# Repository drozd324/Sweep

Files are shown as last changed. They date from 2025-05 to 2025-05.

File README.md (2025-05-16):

Below the first two pictures show my modifications to sweep v2.2 .
Below that again is the original readme.

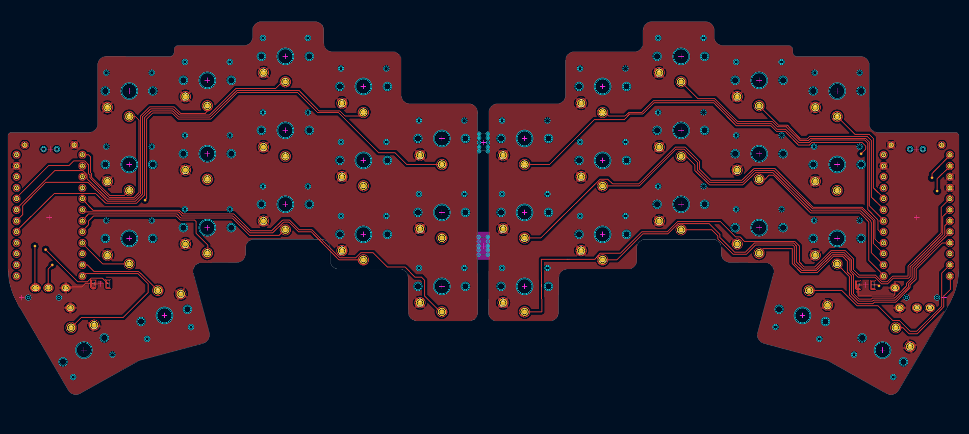
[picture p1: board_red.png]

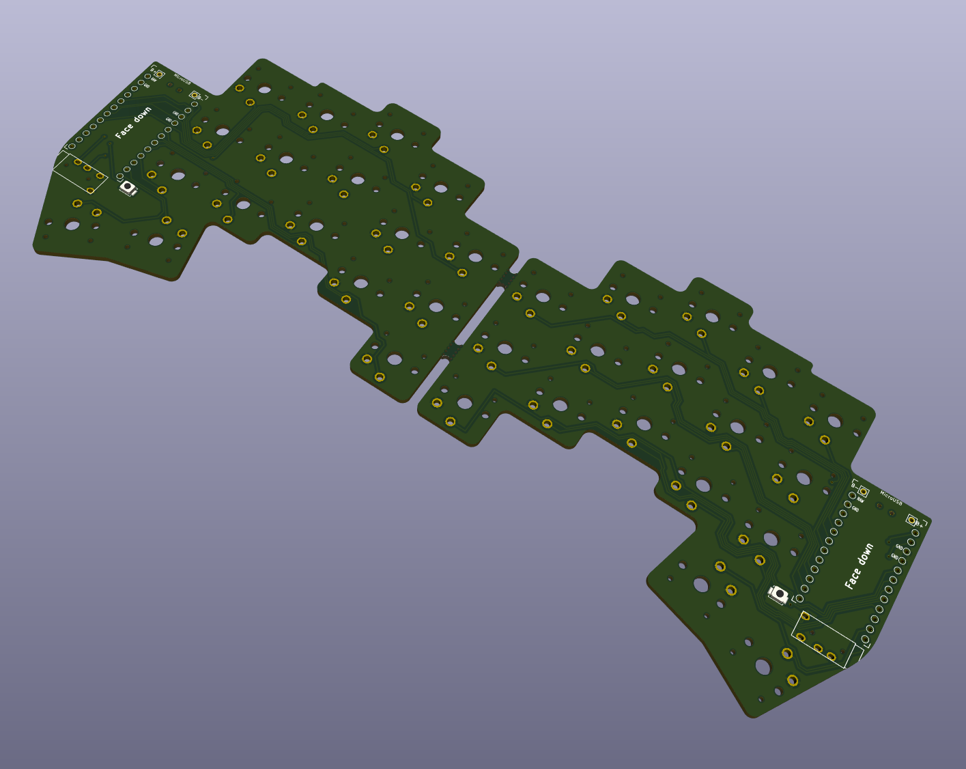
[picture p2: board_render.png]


# Sweep
<!--
           ___                        ___
      ___ |   | ___ ___      ___ ___ |   | ___
 ___ |   |`___`|   |   |    |   |   |`___`|   | ___
|   |`___`|   |`___`___`    `___`___`|   |`___`|   |
`___`|   |`___`|   |   |    |   |   |`___`|   |`___`
|   |`___`|   |`___`___`    `___`___`|   |`___`|   |
`___`|   |`___`|   |   |    |   |   |`___`|   |`___`
|   |`___`     `___`___`    `___`___`     `___`|   |
`___`           ___ ___      ___ ___           `___`
               |   |   |    |   |   |
               `___`___`    `___`___`
-->
>  sweep-hero  
> <sub>Bluetooth Sweep 2 + MBK Legend Keycaps</sub>

<span>
  <a href="https://discord.gg/czXcTXbsgU">
    
  </a>
  
  
  
</span>

## What is sweep?

Sweep is a version of the more fabulous [Ferris](https://github.com/pierrechevalier83/ferris) by [Pierre Chevalier](https://github.com/pierrechevalier83/) that uses a daughter board like a promicro, elite-c, bit-c, nice!nano etc. instead of using onboard components.

## What are the different types?

⭐ Sweep 2 - Recommended Choc v1 board with all the features.  
⭕ Sweep Half Swept - Same as Sweep 2, but with a reversible pro-micro footprint.  
⭕ Sweep Bling MX - An MX only Sweep that features Kailh's hotswap sockets and a stacked case.  
⭕ Sweep Bling LP - A Choc v1 only Sweep that features Kailh's hotswap sockets.  
⭕ Sweep High - Same as the Sweep 2, but trades choc spacing for compatibility with more switches and keycaps.  
⭕ Sweep High M - A soldered MX only Sweep, with a reversible PCB design.  
⭕ Sweep Mini - The only version that supports Choc minis.  

| Device | On/Off Switch<sup>[1]</sup> | Reversible PCB<sup>[2]</sup> | Choc V1 | Choc V2 | Choc Mini | MX & Alps | Choc Spacing<sup>[3]</sup> | Tenting<sup>[4]</sup> | Hot Swap |
| :--- | :---: | :---: | :---: | :---: | :---: | :---: | :---: | :---: | :---: |
| Sweep2.x | ✔ | | ✔ | | | | ✔ | ✔ | Mill-Max (optional) |
| Sweep Bling LP | ✔ | | ✔ | | | | ✔ | ✔ | Kailh (required) |
| Sweep Bling MX | ✔ | ✔ | | | | ⚠<br/><sup>[5]</sup> | | ✔ | Kailh (required) |
| Sweep High | ✔ | | ✔ | ✔ | | ✔ | | ✔ |
| Sweep High M | ✔ | ✔ | | | | MX | | ✔ | |
| Sweep Half Swept  | ✔ | ✔ | ✔ | | | | ✔ | ✔ | Mill-Max (optional) |
| Sweep Mini | | ✔ | | | ✔ | | ✔ | |

> Note: All versions support bluetooth with Nice!Nano

*<sup>[1]</sup> An on/off switch is recommended for bluetooth builds.*  
*<sup>[2]</sup> With a reversible PCB it's easier to make mistakes during assembly, but it allows you to purchase less boards.*  
*<sup>[3]</sup> Choc spaced boards have the switches in a tighter grid. This provides a better final look but is only compatible with some choc keycaps. (e.g. MBK)*  
*<sup>[4]</sup> Supports splitkb's [tenting puck.](https://splitkb.com/products/tenting-puck?_pos=1&_psq=tenting%20&_ss=e&_v=1.0)*  
*<sup>[5]</sup> MX + kailh hotswap ONLY. Alps are NOT supported.*  

## Components list

To build and use a Sweep you will need:

* 1x PCB Kit
* 2x promicro compatible boards or 2 nice!nanos.
* 34 switches of a compatible type (refer to the compatibility table)
* 34 keycaps
* 2x reset switches (optional; [B3U-1000P(M)](https://github.com/davidphilipbarr/Sweep/issues/20))
* Some little rubber feet/bumpers
* 2x power switches (optional if supported; MSK 12C02)
* 1x TRRS (not TRS!) cable (wired build only)
* 2x TRRS Jack [PJ-320A] (wired build only)
* 1 USB Cable (depends on your micro-controller choice)

## How do I make this thing?

<a href="https://www.youtube.com/watch?v=fBPu7AyDtkM" target="_blank">
  
</a>

## Firmware

The firmware can be found [with the Ferris  firmware as part of QMK](https://github.com/qmk/qmk_firmware/tree/master/keyboards/ferris/sweep).

Firmware for zmk and bluemicro_ble is called ["Cradio"](https://zmk.dev/docs/hardware/).

## Who made this?

* [Pierre Chevalier](https://github.com/pierrechevalier83)
* [David Barr](https://github.com/davidphilipbarr)
* [Ibnu Daru Aji](https://github.com/ibnuda/)
* [Duccio](https://github.com/duckyb)

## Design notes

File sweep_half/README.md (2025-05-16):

# Sweep Half Swept

| Front | Back |
| --- | --- |
|  |  |

Half of a Sweep2 with a reversible micro-controller footprint.

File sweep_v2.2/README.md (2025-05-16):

# Sweep2



This is the main Choc v1 board we all know and love.

## Ordering The PCB

To order the PCB the following settings are recommended<sup>1,2</sup>: 

|Detail|Value|
|---|---|
|Gerber file|`sweepv2.X_gerber.zip`|
|Base material|FR-4|
|Layers|2|
|Dimension|216.9mm x 86.9mm|
|Different design|2|
|Delivery format|Panel by customer|
|PCB thickness|1.6mm|
|PCB color|(Personal preference)|
|Silkscreen|(Personal preference)|
|Surface finish|(Personal preference)|
|Outer copper weight|1oz|
|Gold Fingers|No|
|Confirm production file|No|
|Castellated holes|No|
|Remove order number|Yes|

1: Settings are for [JLCPCB](https://jlcpcb.com/), but could work for other manufacturers.

2: Settings are taken from [Kyek's video guide](https://www.youtube.com/watch?v=fBPu7AyDtkM&t=17s).

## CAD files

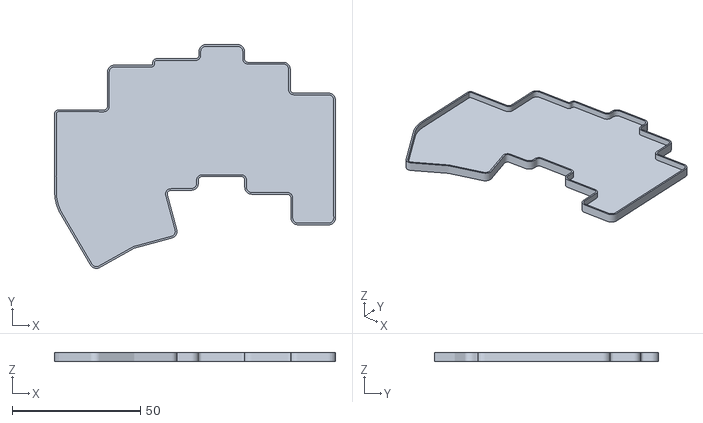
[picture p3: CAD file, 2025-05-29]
sweep_v2.2/my_sweep_case-case0.001.stl
109.6 x 87.3 x 3.60

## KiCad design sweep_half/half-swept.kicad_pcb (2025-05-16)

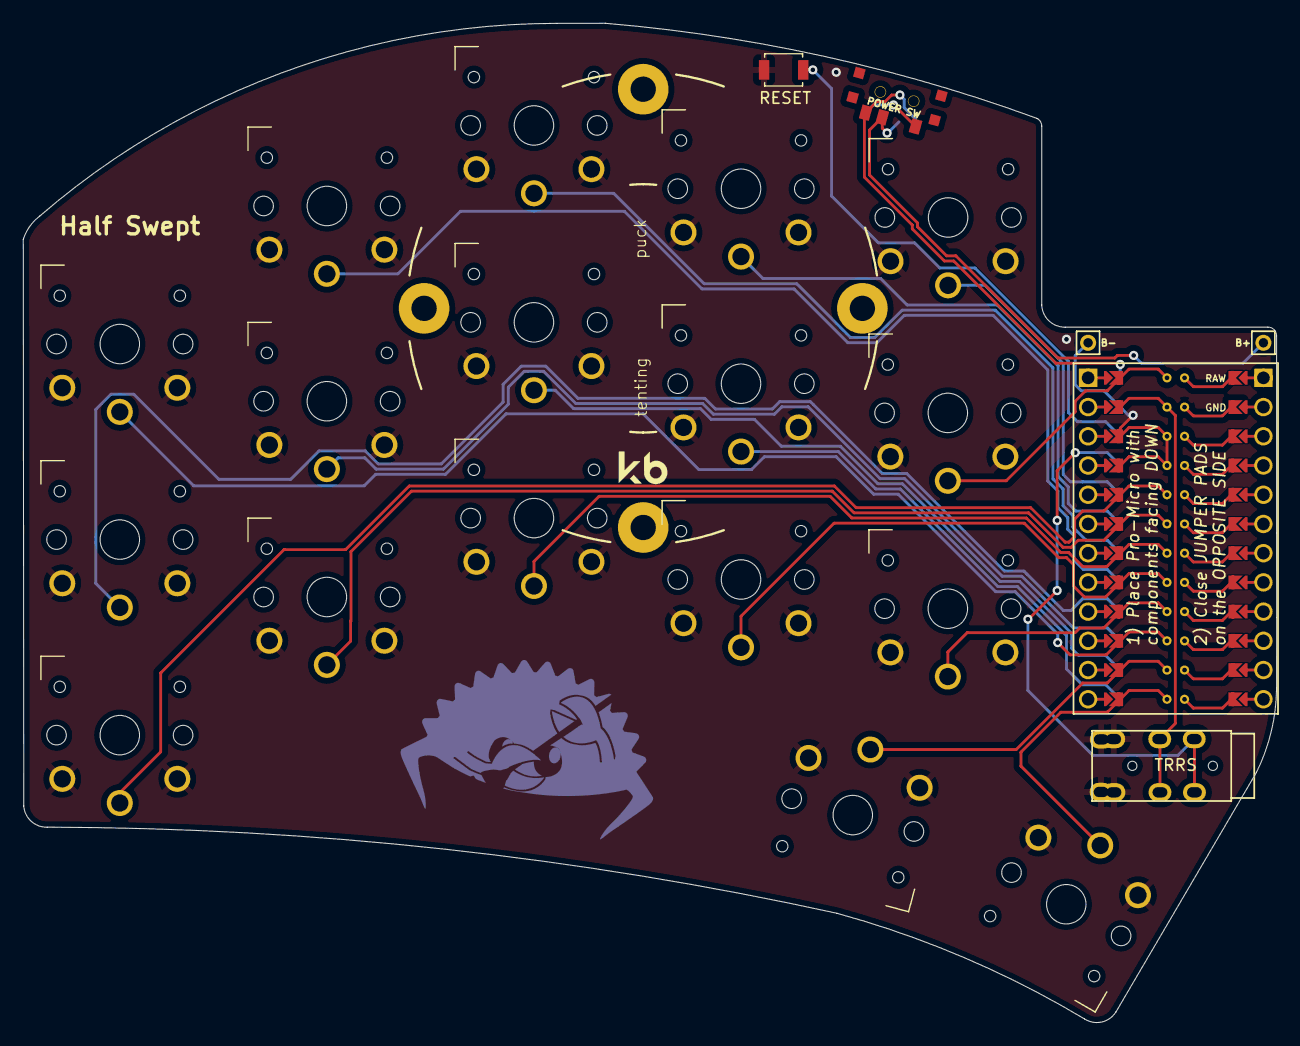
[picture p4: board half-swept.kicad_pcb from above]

Board: 2 copper layers, 109.0 x 86.9 mm, 23 parts (0 on the bottom side), 23 nets.

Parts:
B+: MountingHole_Pad; 1pin_conn
B-: MountingHole_Pad; 1pin_conn
J2: AudioJack4dpb; TRRS-PJ-DPB2
POWER SW: SW_SPDT; SPDT_C128955
RSW2: SW_Push; Tactile-Switch_SMT
SW1, SW2, SW3, SW4, SW5, SW6, SW7, SW8, SW9, SW10, SW11, SW12, SW13, SW14, SW15, SW16, SW17: SW_Push; SW_PG1350_rev_DPB
U1: ProMicro-kbd; ProMicro_jumpers_facedown

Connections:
BT+_r: B+.1, POWER SW.2
Switch1: SW1.1, U1.10
Switch2: SW2.1, U1.17
Switch3: SW3.1, U1.18
Switch4: SW4.1, U1.19
Switch5: SW5.1, U1.20
Switch6: SW6.1, U1.16
Switch7: SW7.1, U1.15
Switch8: SW8.1, U1.14
Switch9: SW9.1, U1.13
Switch10: SW10.1, U1.1
Switch11: SW11.1, U1.5
Switch12: SW12.1, U1.6
Switch13: SW13.1, U1.7
Switch14: SW14.1, U1.8
Switch15: SW15.1, U1.9
Switch16: SW16.1, U1.11
Switch17: SW17.1, U1.12
Switch18: J2.R1, U1.2
gnd: B-.1, J2.S, J2.T, RSW2.1, RSW2.2, SW1.2, SW2.2, SW3.2, SW4.2, SW5.2, SW6.2, SW7.2, SW8.2, SW9.2, SW10.2, SW11.2, SW12.2, SW13.2, SW14.2, SW15.2, SW16.2, SW17.2, U1.3, U1.4, U1.23
raw: POWER SW.3, U1.24
reset: RSW2.1, RSW2.2, U1.22
vcc: J2.R2, U1.21

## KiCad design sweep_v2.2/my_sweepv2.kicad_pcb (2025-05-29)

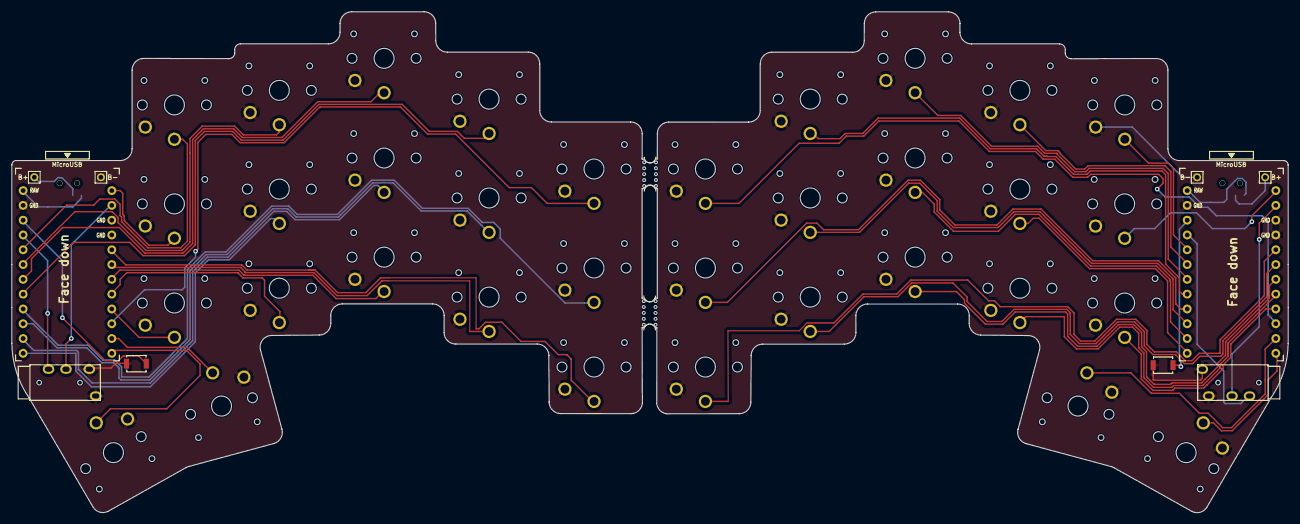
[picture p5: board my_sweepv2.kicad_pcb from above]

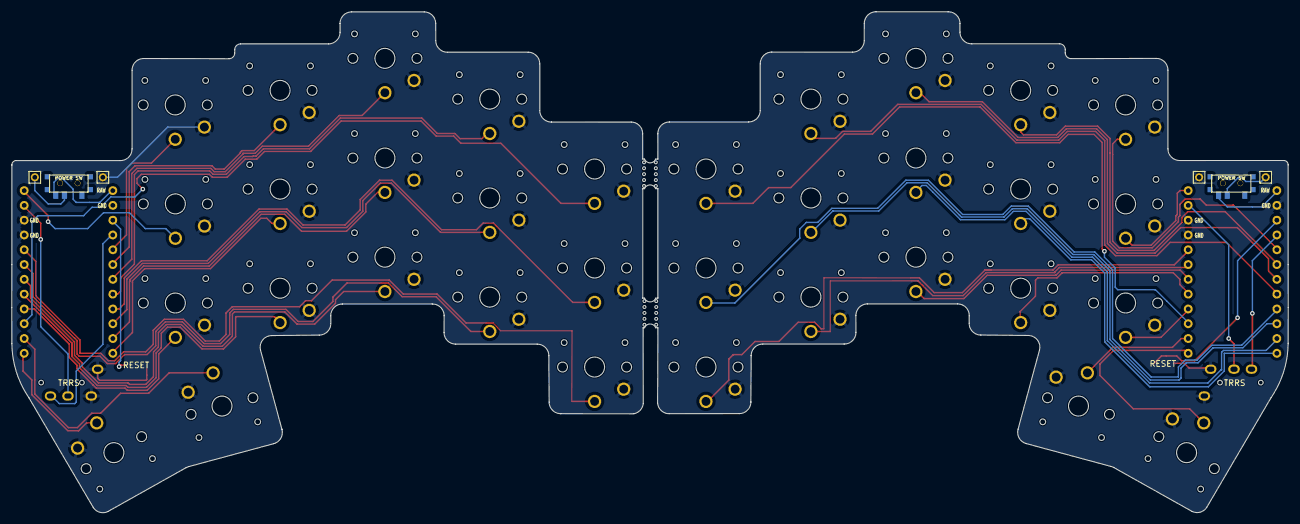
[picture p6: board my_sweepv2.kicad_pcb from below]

Board: 2 copper layers, 219.1 x 86.0 mm, 48 parts (2 on the bottom side), 43 nets.

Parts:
B+: MountingHole_Pad; 1pin_conn
B+#2: MountingHole_Pad; 1pin_conn
B-: MountingHole_Pad; 1pin_conn
B-#2: MountingHole_Pad; 1pin_conn
J1, J2: AudioJack4dpb; TRRS-PJ-320A
POWER SW: SW_SPDT; SPDT_C128955
POWER SW#2: SW_SPDT; SPDT_C128955
RSW1, RSW2: SW_Push; SW_SPST_B3U-1000P
SW2, SW2_r1, SW3, SW3_r1, SW4, SW4_r1, SW5, SW5_r1, SW6, SW6_r1, SW7_r1, SW8, SW8_r1, SW9, SW9_r1, SW10, SW11, SW11_r1, SW12, SW12_r1, SW13_r1, SW14, SW15, SW15_r1, SW16, SW16_r1, SW17, SW17_r1, SW18, SW18_r1, SW20, SW20_r1, SW21, SW21_r1: SW_Push; choc-v1-with-millmax
U1, U2: ProMicro-kbd; ProMicro_v3_min
mouse-bite-2mm-slot, mouse-bite-2mm-slot#2: VAL**; mouse-bite-5mm-slot-with-space-for-track

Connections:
BT+: B+#2.1, POWER SW#2.2
BT+_r: B+.1, POWER SW.2
Switch1: SW2.1, U1.10
Switch1_r: SW2_r1.1, U2.10
Switch2: SW3.1, U1.17
Switch2_r: SW3_r1.1, U2.17
Switch3: SW4.1, U1.18
Switch3_r: SW4_r1.1, U2.18
Switch4: SW5.1, U1.19
Switch4_r: SW5_r1.1, U2.19
Switch5: SW6.1, U1.20
Switch5_r: SW6_r1.1, U2.20
Switch6: SW8.1, U1.16
Switch6_r: SW7_r1.1, U2.16
Switch7: SW9.1, U1.15
Switch7_r: SW8_r1.1, U2.15
Switch8: SW10.1, U1.14
Switch8_r: SW9_r1.1, U2.14
Switch9: SW11.1, U1.13
Switch9_r: SW11_r1.1, U2.13
Switch10: SW12.1, U1.1
Switch10_r: SW12_r1.1, U2.1
Switch11: SW14.1, U1.5
Switch11_r: SW13_r1.1, U2.5
Switch12: SW15.1, U1.6
Switch12_r: SW18_r1.1, U2.6
Switch13: SW16.1, U1.7
Switch13_r: SW15_r1.1, U2.7
Switch14: SW17.1, U1.8
Switch14_r: SW16_r1.1, U2.8
Switch15: SW18.1, U1.9
Switch15_r: SW17_r1.1, U2.9
Switch16: SW21.1, U1.11
Switch16_r: SW21_r1.1, U2.11
Switch17: SW20.1, U1.12
Switch17_r: SW20_r1.1, U2.12
Switch18: J2.R1, U1.2
Switch18_r: J1.R1, U2.2
gnd: B-.1, B-#2.1, J1.S, J1.T, J2.S, J2.T, RSW1.1, RSW2.1, SW2.2, SW2_r1.2, SW3.2, SW3_r1.2, SW4.2, SW4_r1.2, SW5.2, SW5_r1.2, SW6.2, SW6_r1.2, SW7_r1.2, SW8.2, SW8_r1.2, SW9.2, SW9_r1.2, SW10.2, SW11.2, SW11_r1.2, SW12.2, SW12_r1.2, SW13_r1.2, SW14.2, SW15.2, SW15_r1.2, SW16.2, SW16_r1.2, SW17.2, SW17_r1.2, SW18.2, SW18_r1.2, SW20.2, SW20_r1.2, SW21.2, SW21_r1.2, U1.3, U1.4, U1.23, U2.3, U2.4, U2.23
raw: POWER SW.3, POWER SW#2.3, U1.24, U2.24
reset: RSW1.2, U1.22
reset_r: RSW2.2, U2.22
vcc: J1.R2, J2.R2, U1.21, U2.21

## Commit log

2025-05-16 Removed files I wasnt using and modified the fill of both v2.2 and half
    [ferris-sweep-compact.kicad_pcb, ferris-sweep-compact.sch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]
2025-05-16 cleaning and added pictures
    [half-swept-B_Cu.gbr, half-swept-B_Mask.gbr, half-swept-B_Paste.gbr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]
2025-05-29 fixed trace outside of pcb, started making case
    [my_sweep_case-case0.001.stl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]
